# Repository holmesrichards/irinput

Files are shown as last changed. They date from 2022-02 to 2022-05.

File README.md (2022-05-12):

# Barton IR Input

This is a modified version, in Kosmo format, of the [Barton Musical Circuits 078 IR Input](https://www.bartonmusicalcircuits.com/irin/index.html) synth module. Barton describes the original version as follows:

> This module is designed to allow infrared light sources to interact with your synthesizer. The most common household sources of infrared light are fire and remote controls. Infrared LEDs are also readily available to DIYers who wanted to experiment with creating new devices for controlling synthesizers through this module.

The infrared phototransistor that picks up the IR light may be AC or DC coupled to the circuit. Outputs are a CV proportional to the IR signal and a gate that turns on when the CV rises above a threshold set with a panel pot. Another panel pot sets the phototransistor sensitivity.

Modifications to Barton's design are as follows:

* Added 3.5 mm TRS jack for a cable connecting to an external phototransistor and a switch to select internal or external PT. This allows using candles, lighters, etc. to control the synth while not having to have them right in front of it.
* Added gain knob to control gain of amplifier stage. The sensitivity pot (what Barton calls "bias") does vary the size of the signal but gives a small window between too small (no output) and too large (saturated). In AC coupled mode, the size of the AC component may be small, e.g. a few hundred mV, even when the sensitivity pot is set to just below saturation; of course the AC component disappears if the sensitivity pot is then raised further. The gain pot may be used to amplify the AC component to the level of a few volts. In AC mode, the gain range is 1 to 11. In DC mode, the gain pot may be used to help with faint IR sources; the gain range is 1 to 2.
* Added a bicolor indicator LED for the CV output. Brightness is indicative of CV amplitude and color indicates sign (which is positive in DC mode but can go negative in AC mode). 
* Added an indicator LED for saturation. This turns on when the PT emitter voltage is about 10 V. Normally one would want to operate with the sensitivity pot adjusted to just below where this LED comes on continuously while the IR light source is maximum.
* Specified A1M rather than B1M for sensitivity pot.

My modifications, PCB layout, and documentation are licensed Creative Commons Zero (see [LICENSE](LICENSE)). This license is not intended to apply to Michael Barton's intellectual property and no violation of any applicable copyright is intended. Do not use this design for any commercial purpose without first obtaining Barton's permission.

## Current draw
12 mA +12 V, 8 mA -12 V

## Photos

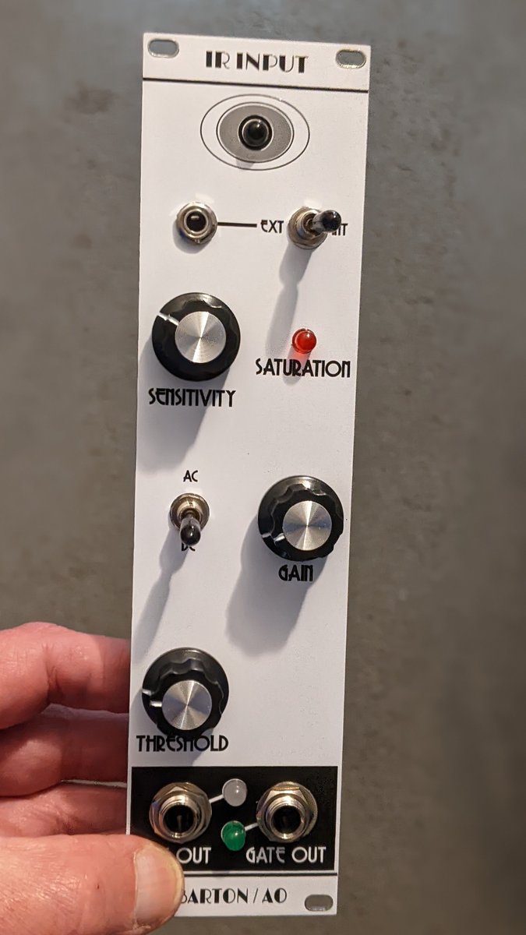
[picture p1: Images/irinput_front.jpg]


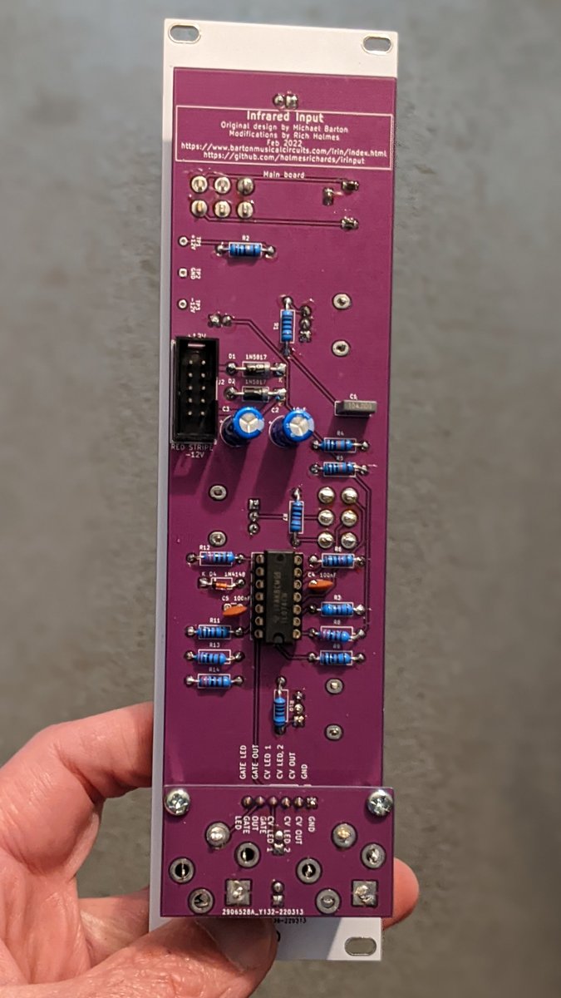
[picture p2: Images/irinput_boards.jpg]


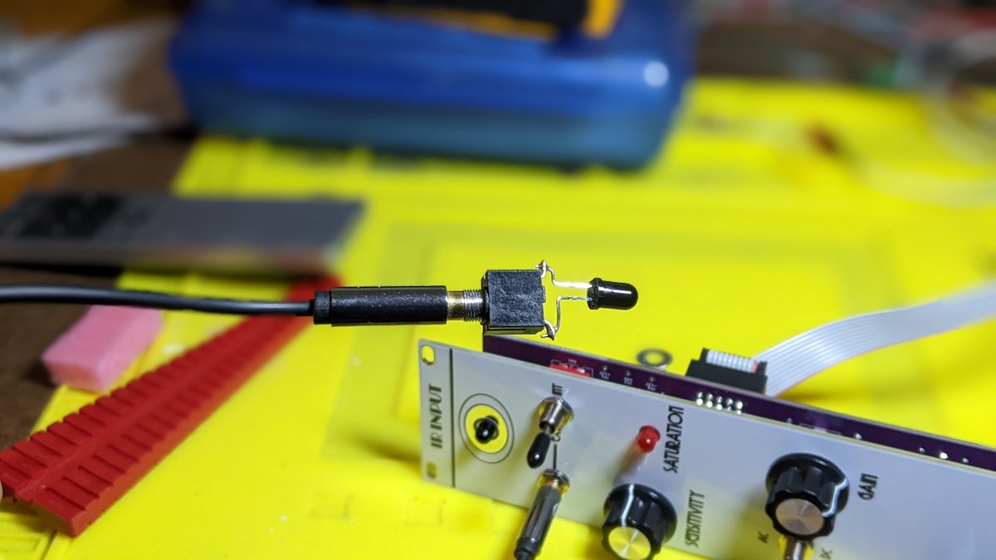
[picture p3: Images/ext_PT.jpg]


## Documentation

* [Schematic](Docs/irinput.pdf)
* PCB layout: [front](Docs/_layout_front.pdf), [back](Docs/_layout_back.pdf)
* [BOM](Docs/irinput_bom.md)
* [Build notes](Docs/irinput_build.md)
* [Blog post 1](https://analogoutputblog.wordpress.com/2022/02/22/playing-with-fire/), [blog post 2](https://analogoutputblog.wordpress.com/2022/03/27/ir-input/)

## GitHub repository

* [https://github.com/holmesrichards/irinput](https://github.com/holmesrichards/irinput)

## Submodules

This repo uses submodules aoKicad and Kosmo_panel, which provide needed libaries for KiCad. To clone:

```
git clone git@github.com:holmesrichards/ir_input.git
git submodule init
git submodule update
```

Alternatively do

```
git clone --recurse-submodules git@github.com:holmesrichards/ir_input.git
```

Or if you download the repository as a zip file, you must also click on the "aoKicad" and "Kosmo\_panel" links on the GitHub page (they'll have "@ something" after them) and download them as separate zip files which you can unzip into this repo's aoKicad and Kosmo\_panel directories.

If desired, copy the files from aoKicad and Kosmo\_panel to wherever you prefer (your KiCad user library directory, for instance, if you have one). Then in KiCad, add symbol libraries 

```
aoKicad/ao_symbols
Kosmo_panel/Kosmo
```
and footprint libraries 
```
aoKicad/ao_tht
Kosmo_panel/Kosmo_panel.
```

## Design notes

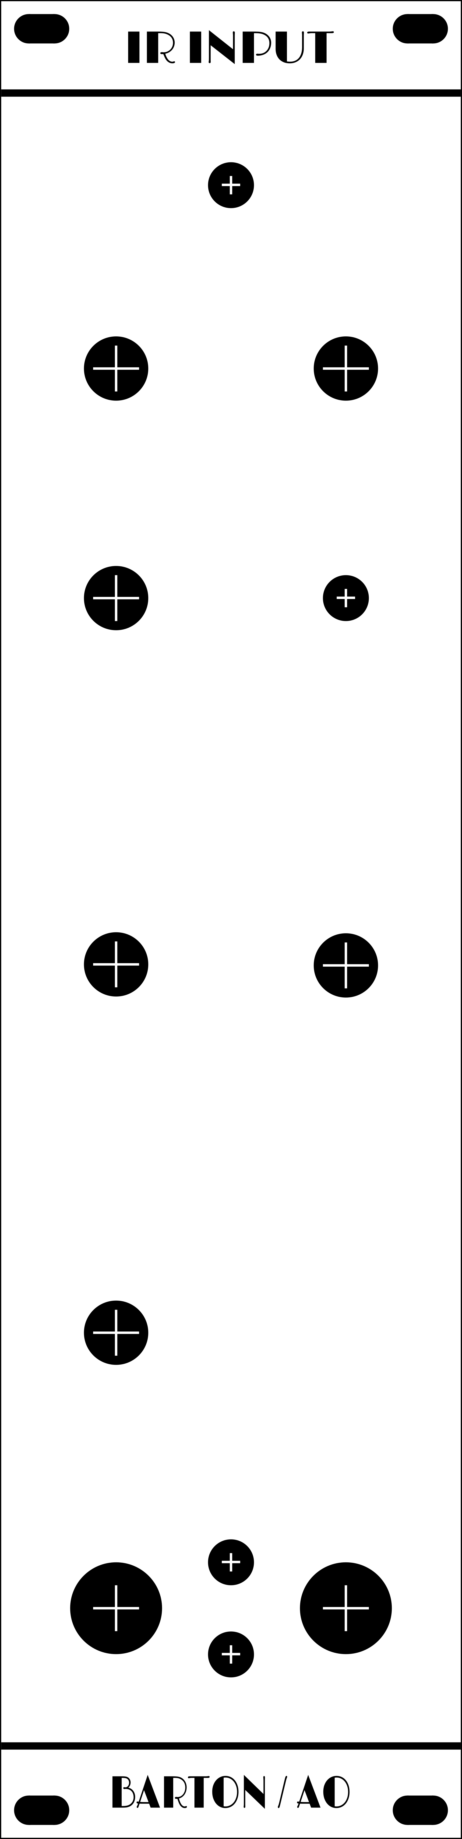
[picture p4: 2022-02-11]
Images/irinput_panel_holes.png

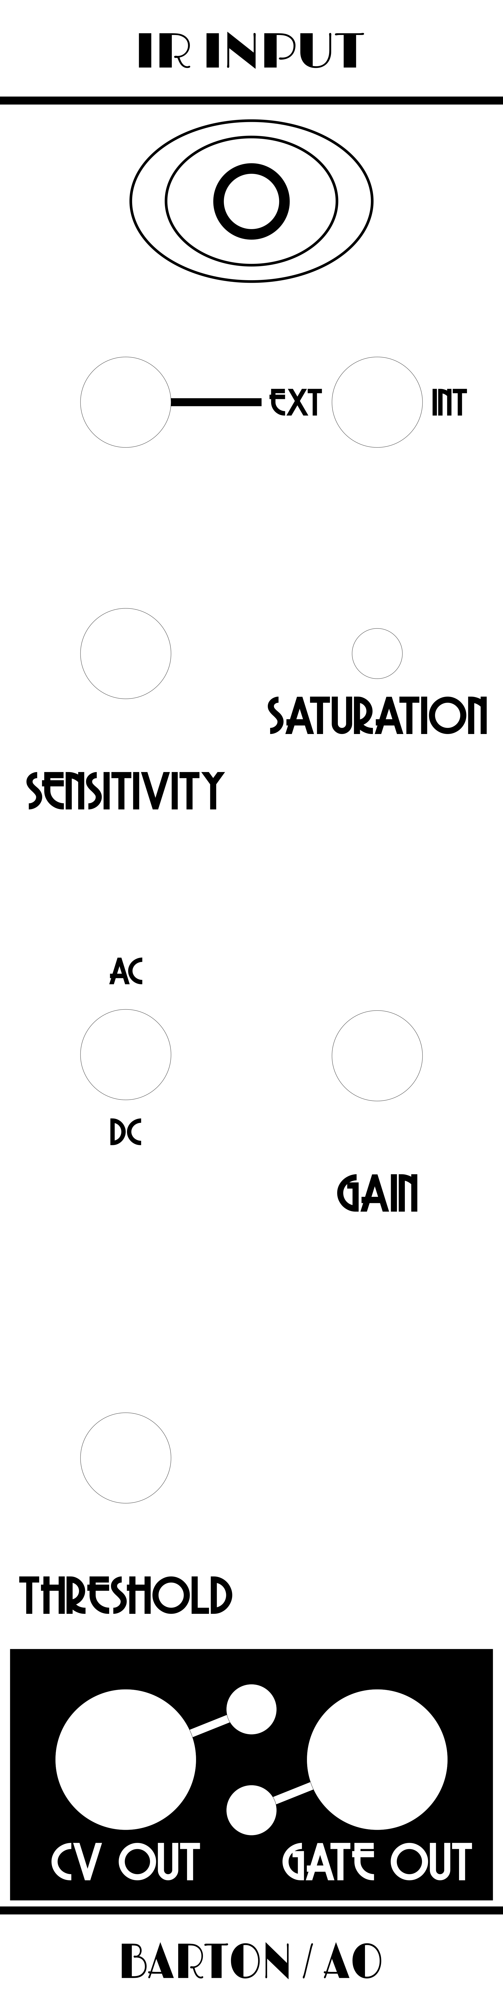
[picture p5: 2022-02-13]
Images/irinput_panel_art.png

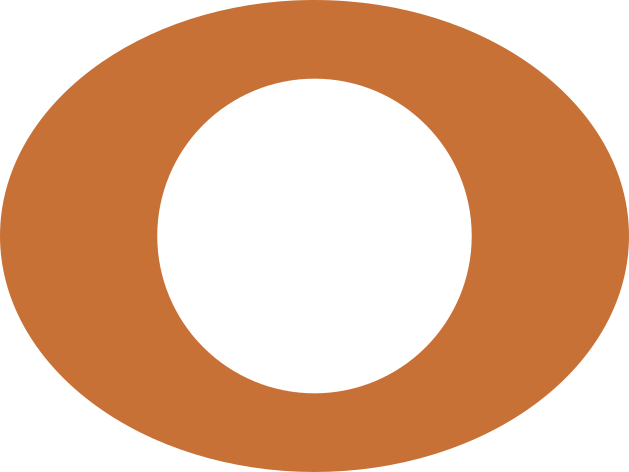
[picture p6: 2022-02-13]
Images/irinput_panel_art_more.png

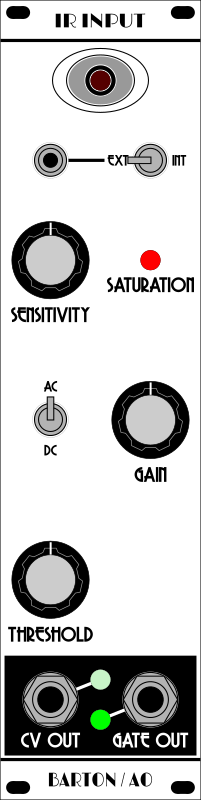
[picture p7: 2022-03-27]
Images/irinput_panel.png

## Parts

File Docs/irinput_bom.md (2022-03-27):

# irinput.kicad_sch BOM

Sun 27 Mar 2022 07:12:55 AM EDT

Generated from schematic by Eeschema 6.0.4-6f826c9f35~116~ubuntu20.04.1

**Component Count:** 40

| Refs | Qty | Component | Description | Vendor | SKU |
| ----- | --- | ---- | --- | ---- | ---- |
| C1 | 1 | 100nF | Film capacitor | Tayda |  |
| C2, C3 | 2 | 10uF | Electrolytic capacitor | Tayda | A-4349 |
| C4, C5 | 2 | 100nF | Ceramic capacitor | Tayda | A-553 |
| D1, D2 | 2 | 1N5817 | Schottky Barrier Rectifier Diode, DO-41 | Tayda | A-159 |
| D3 | 1 | LED_red | Light emitting diode | Tayda | A-1554 |
| D4 | 1 | 1N4148 | Standard switching diode, DO-35 | Tayda | A-157 |
| D5 | 1 | LED_green | Light emitting diode | Tayda | A-1553 |
| D6 | 1 | LED_Dual | Dual LED, bidirectional |  |  |
| J1, J3 | 2 | AudioJack3 | 3.5 mm Audio Jack, 3 Poles (Stereo / TRS) | Tayda | A-1121 |
| J2 | 1 | Synth_power_2x5 | Shrouded 2x5 pin header | Tayda | A-2939 |
| J4 | 1 | Conn_01x06 | 1x6 pin socket, 2.54 mm |  |  |
| J5 | 1 | Conn_01x06 | 1x6 pin header, 2.54 mm |  |  |
| J6, J7 | 2\* | AudioJack2 | 1/4" Audio Jack, 2 Poles (Mono / TS) | Tayda | A-1121 |
| Q1, Q2 | 2\* | TOPS-050 | NPN phototransistor, collector/emitter | Tayda |  |
| R1 | 1 | 100R | Resistor | Tayda |  |
| R2 | 1 | 10R | Resistor | Tayda |  |
| R3 | 1 | 68k | Resistor | Tayda |  |
| R4, R5 | 2 | 100k | Resistor | Tayda |  |
| R6 | 1 | 18k | Resistor | Tayda |  |
| R7 | 1 | 10k | Resistor | Tayda |  |
| R8, R12, R14 | 3 | 2.2k | Resistor | Tayda |  |
| R9, R10, R11 | 3 | 1k | Resistor | Tayda |  |
| R13 | 1 | 2.7k | Resistor | Tayda |  |
| RV1 | 1 | A1M | 9 mm PCB mount potentiometer | Tayda |  |
| RV2, RV3 | 2 | B100k | 9 mm PCB mount potentiometer | Tayda |  |
| SW1, SW2 | 2 | SW_DPDT | Switch, dual pole double throw, on-on |  |  |
| U1 | 1 | TL074 | Quad operational amplifier, DIP-14 | Tayda | A-1138 |
| | 1 | | 14 pin DIP socket | Tayda | |
| | 3 | | knobs | | |

M3 screws, spacers, washers

\* One 3.5 mm stereo jack and one phototransistor are used to make a cable mounted external IR pickup.

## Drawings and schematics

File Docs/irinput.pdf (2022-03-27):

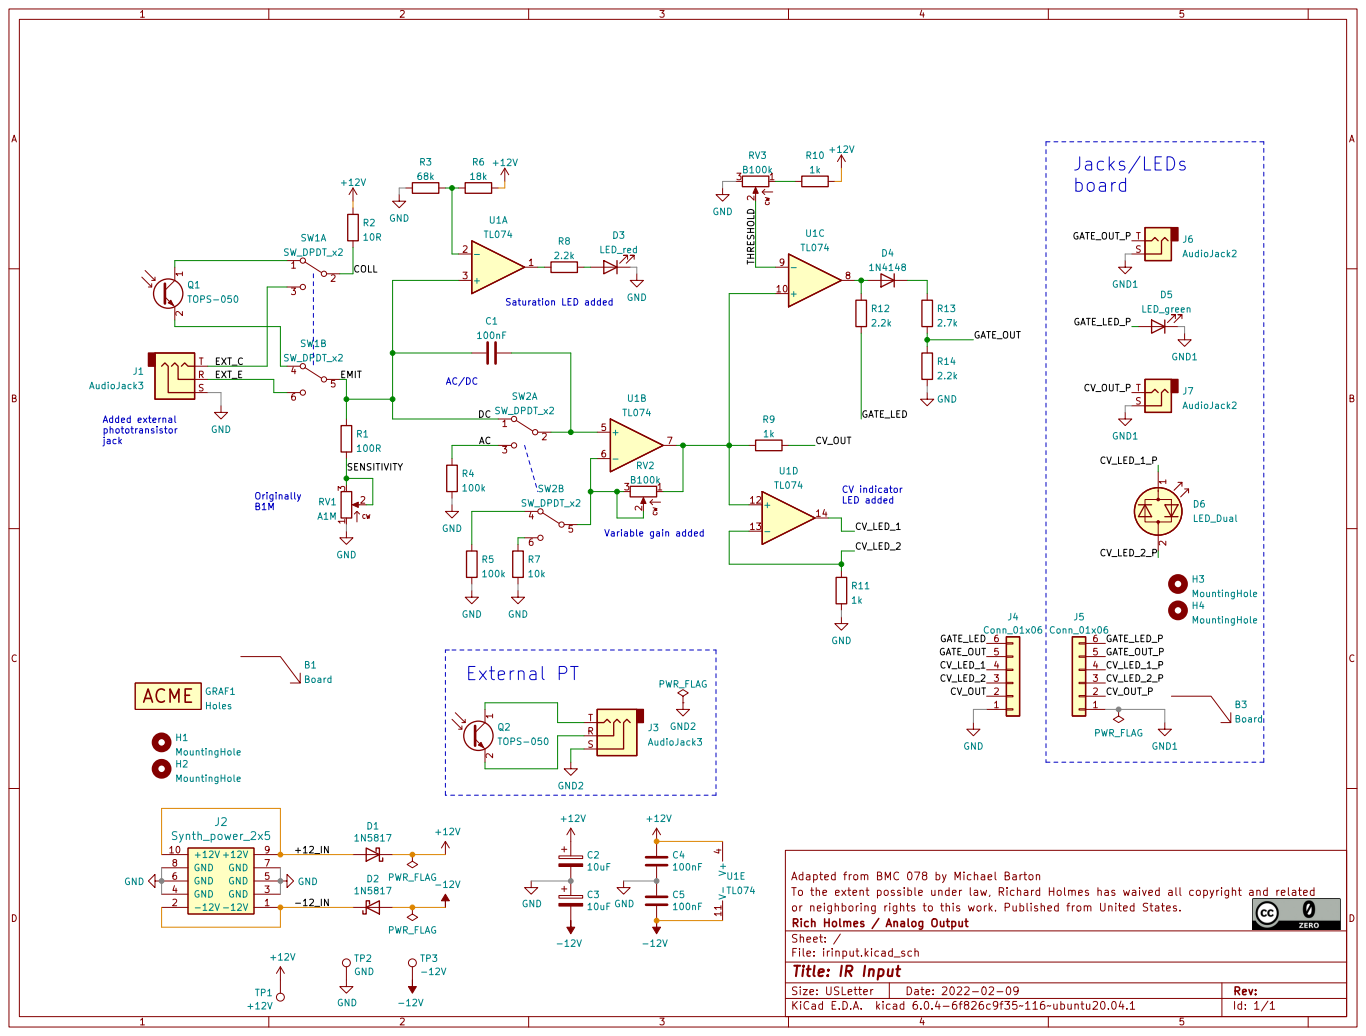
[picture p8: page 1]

or neighboring rights to this work. Published from United States.
File: irinput.kicad_sch Sheet: / Rich Holmes / Analog Output

Id: 1/1 Title: IR Input

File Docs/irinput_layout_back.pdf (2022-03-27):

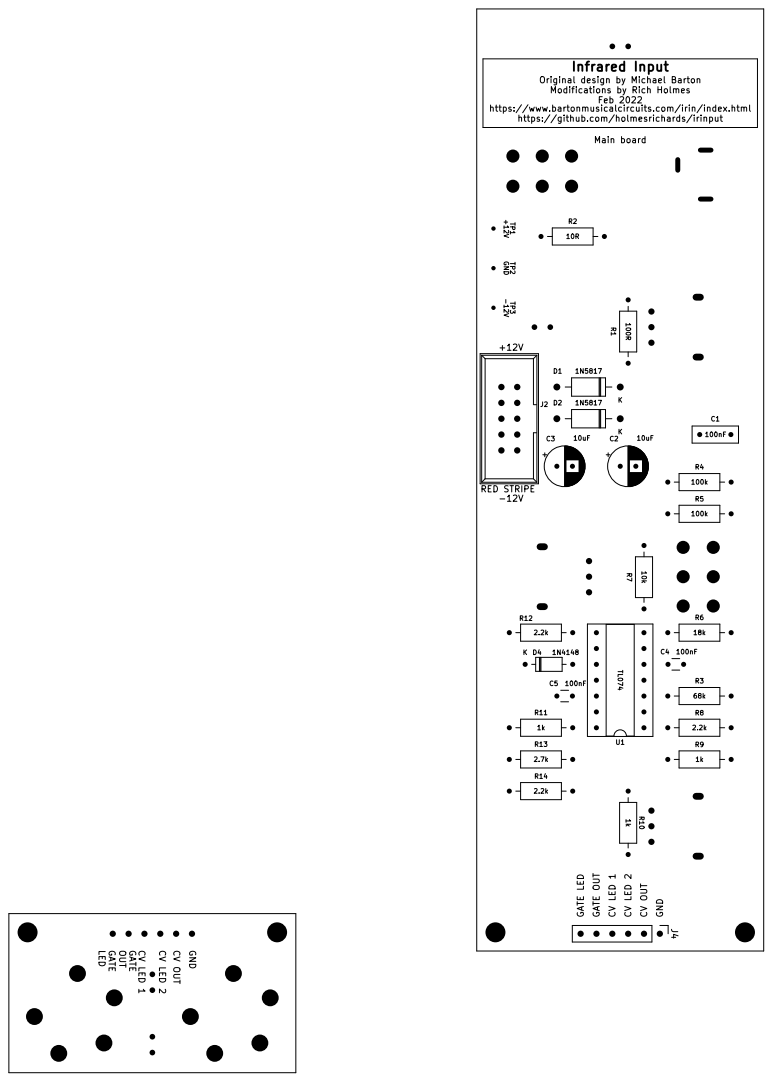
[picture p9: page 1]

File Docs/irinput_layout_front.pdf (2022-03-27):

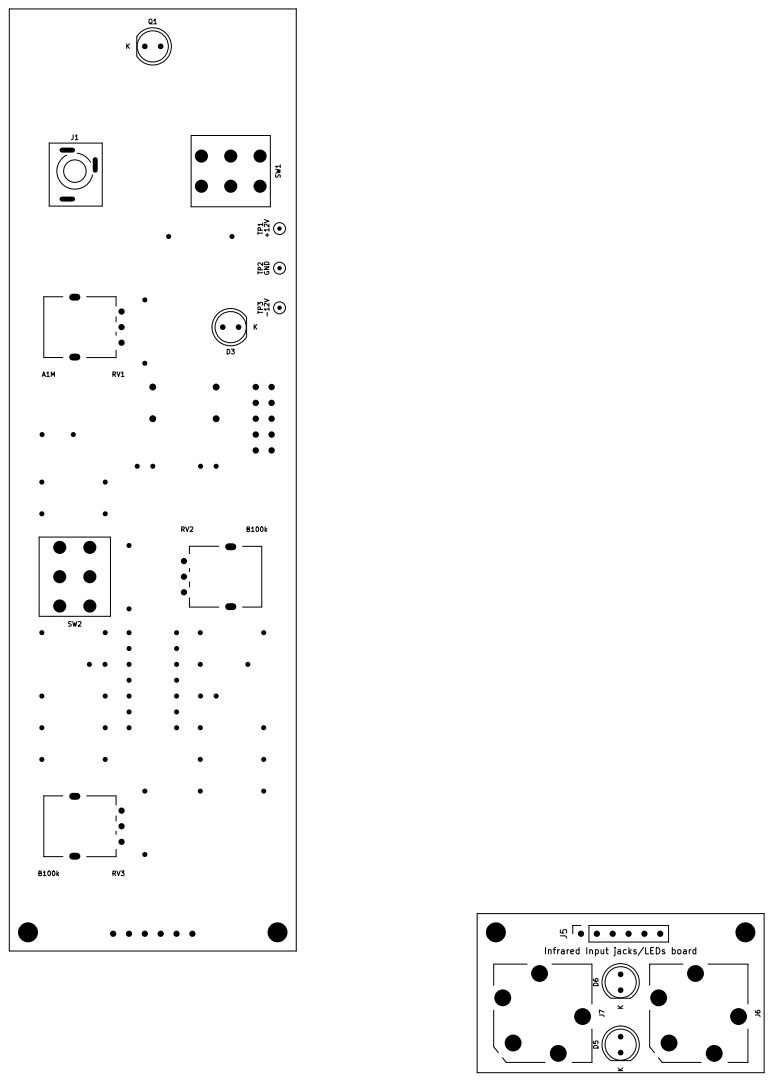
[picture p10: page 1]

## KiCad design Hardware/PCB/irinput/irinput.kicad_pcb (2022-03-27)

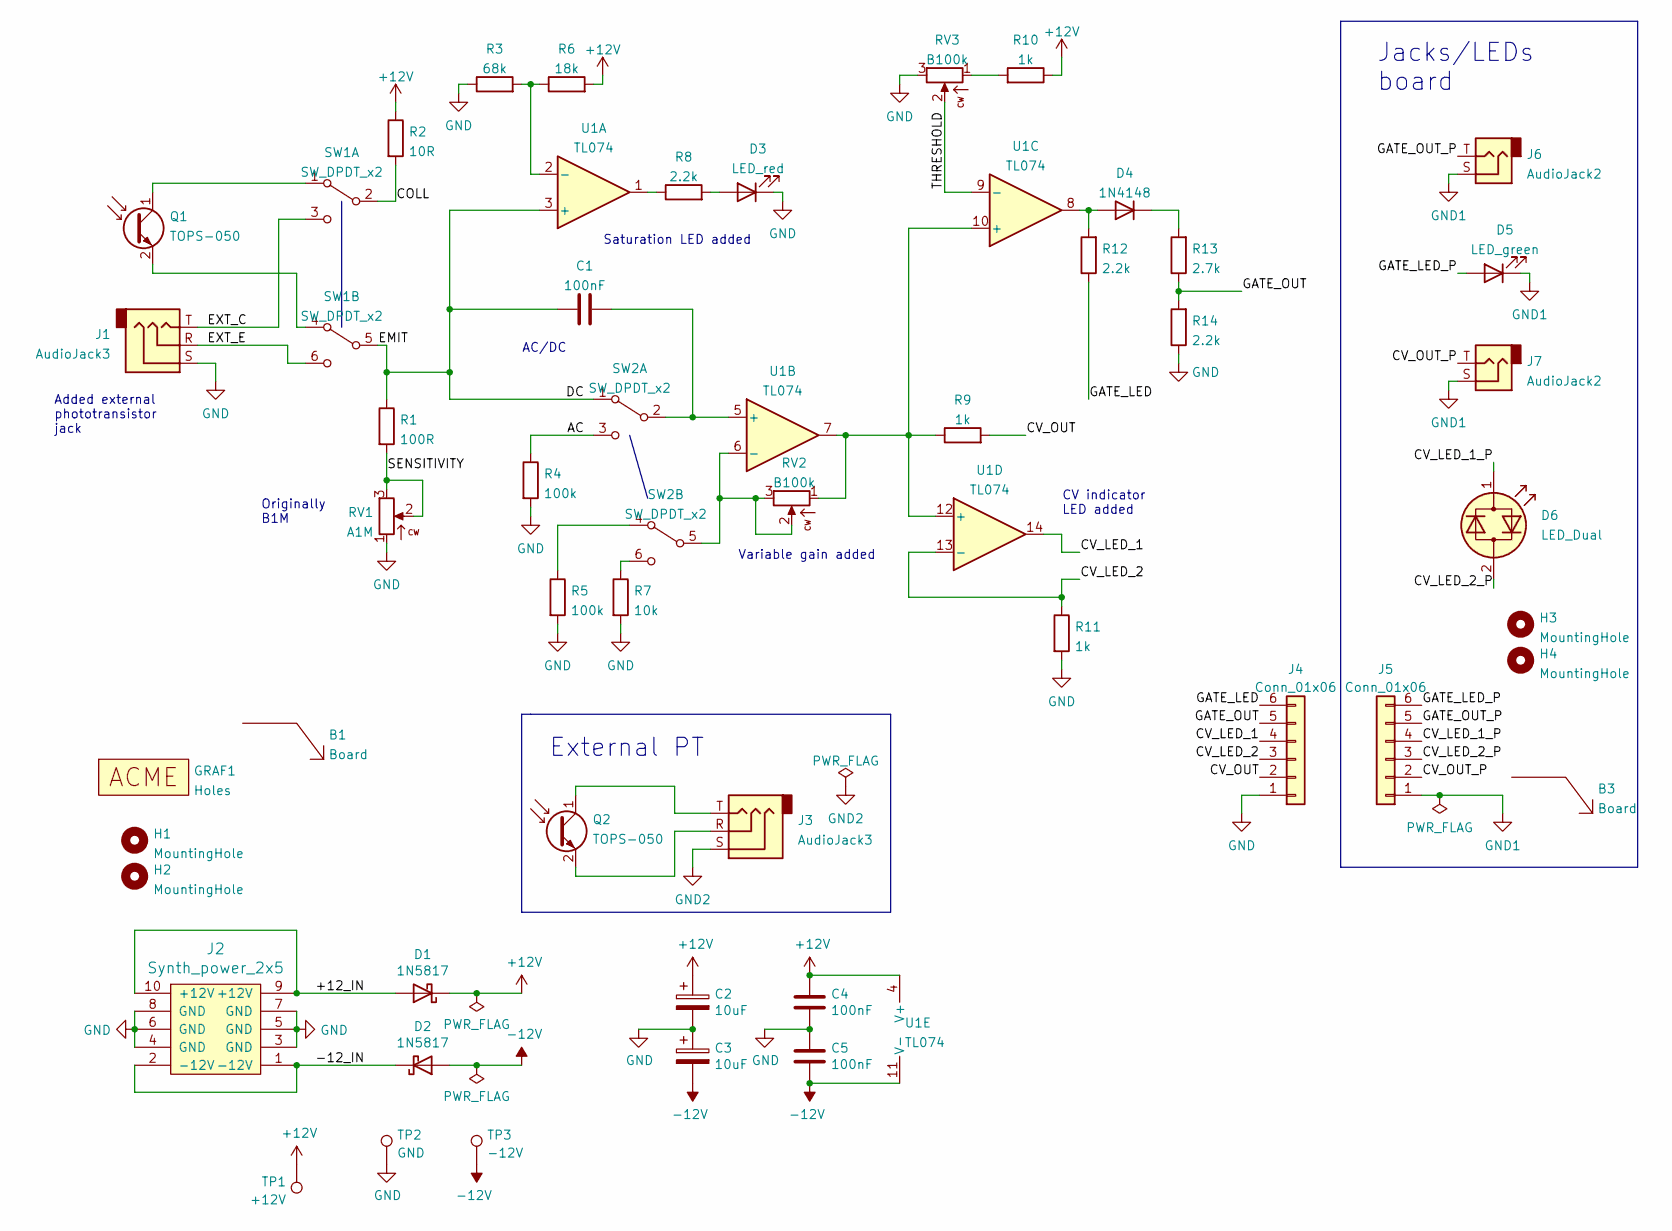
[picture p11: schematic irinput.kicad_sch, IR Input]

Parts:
B1, B3: Board; Board_Marker
C1: 100nF; C_Rect_L7.2mm_W2.5mm_P5.00mm_FKS2_FKP2_MKS2_MKP2
C2, C3: 10uF; CP_Radial_D6.3mm_P2.50mm
C4, C5: 100nF; C_Disc_D3.0mm_W1.6mm_P2.50mm
D1, D2: 1N5817; D_DO-41_SOD81_P10.16mm_Horizontal
D3: LED_red; LED_D5.0mm
D4: 1N4148; D_DO-35_SOD27_P7.62mm_Horizontal
D5: LED_green; LED_D5.0mm
D6: LED_Dual; LED_D5.0mm
GRAF1: Holes; irinput_panel_holes
H1, H2, H3, H4: MountingHole; MountingHole_3.2mm_M3
J1, J3: AudioJack3; Jack_3.5mm_PJ-301CM
J2: Synth_power_2x5; Power_Header
J4: Conn_01x06; PinHeader_1x06_P2.54mm_Vertical
J5: Conn_01x06; PinSocket_1x06_P2.54mm_Vertical
J6, J7: AudioJack2; Jack_6.35mm_PJ_629HAN
Q1, Q2: TOPS-050; LED_D5.0mm
R1: 100R; R_Axial_DIN0207_L6.3mm_D2.5mm_P10.16mm_Horizontal
R2: 10R; R_Axial_DIN0207_L6.3mm_D2.5mm_P10.16mm_Horizontal
R3: 68k; R_Axial_DIN0207_L6.3mm_D2.5mm_P10.16mm_Horizontal
R4, R5: 100k; R_Axial_DIN0207_L6.3mm_D2.5mm_P10.16mm_Horizontal
R6: 18k; R_Axial_DIN0207_L6.3mm_D2.5mm_P10.16mm_Horizontal
R7: 10k; R_Axial_DIN0207_L6.3mm_D2.5mm_P10.16mm_Horizontal
R8, R12, R14: 2.2k; R_Axial_DIN0207_L6.3mm_D2.5mm_P10.16mm_Horizontal
R9, R10, R11: 1k; R_Axial_DIN0207_L6.3mm_D2.5mm_P10.16mm_Horizontal
R13: 2.7k; R_Axial_DIN0207_L6.3mm_D2.5mm_P10.16mm_Horizontal
RV1: A1M; Potentiometer_Alpha_RD901F-40-00D_Single_Vertical_centered
RV2, RV3: B100k; Potentiometer_Alpha_RD901F-40-00D_Single_Vertical_centered
SW1, SW2: SW_DPDT_x2; DPDT-toggle-switch-1M-seriesx
TP1: +12V; TestPoint_THTPad_D1.5mm_Drill0.7mm
TP2: GND; TestPoint_THTPad_D1.5mm_Drill0.7mm
TP3: -12V; TestPoint_THTPad_D1.5mm_Drill0.7mm
U1: TL074; DIP-14_W7.62mm_Socket_LongPads

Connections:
+12V: C2.1, C4.1, D1.1 (K), R2.1, R6.2, R10.1, TP1.1, U1.4 (V+)
-12V: C3.2, C5.2, D2.2 (A), TP3.1, U1.11 (V-)
/+12_IN: D1.2 (A), J2.9 (+12V), J2.10 (+12V)
/-12_IN: D2.1 (K), J2.1 (-12V), J2.2 (-12V)
/AC: R4.1, SW2.3 (C)
/COLL: R2.2, SW1.2 (B)
/CV_LED_1: J4.4, U1.14
/CV_LED_1_P: D6.1 (KA), J5.4
/CV_LED_2: J4.3, R11.1, U1.13 (-)
/CV_LED_2_P: D6.2 (AK), J5.3
/CV_OUT: J4.2, R9.2
/CV_OUT_P: J5.2, J7.T
/DC: C1.1, R1.1, SW1.5 (B), SW2.1 (A), U1.3 (+)
/EXT_C: J1.T, SW1.3 (C)
/EXT_E: J1.R, SW1.6 (C)
/GATE_LED: J4.6, R12.1
/GATE_LED_P: D5.2 (A), J5.6
/GATE_OUT: J4.5, R13.1, R14.2
/GATE_OUT_P: J5.5, J6.T
/SENSITIVITY: R1.2, RV1.2, RV1.3
/THRESHOLD: RV3.2, U1.9 (-)
GND: C2.2, C3.1, C4.2, C5.1, D3.1 (K), J1.S, J2.3 (GND), J2.4 (GND), J2.5 (GND), J2.6 (GND), J2.7 (GND), J2.8 (GND), J4.1, R3.1, R4.2, R5.2, R7.2, R11.2, R14.1, RV1.1, RV3.3, TP2.1
GND1: D5.1 (K), J5.1, J6.S, J7.S
unnamed: C1.2, SW2.2 (B), U1.5 (+)
unnamed: D3.2 (A), R8.2
unnamed: D4.1 (K), R13.2
unnamed: D4.2 (A), R12.2, U1.8
unnamed: J3.R, Q2.2 (E)
unnamed: J3.T, Q2.1 (C)
unnamed: Q1.1 (C), SW1.1 (A)
unnamed: Q1.2 (E), SW1.4 (A)
unnamed: R3.2, R6.1, U1.2 (-)
unnamed: R5.1, SW2.4 (A)
unnamed: R7.1, SW2.6 (C)
unnamed: R8.1, U1.1
unnamed: R9.1, RV2.1, U1.7, U1.10 (+), U1.12 (+)
unnamed: R10.2, RV3.1
unnamed: RV2.2, RV2.3, SW2.5 (B), U1.6 (-)

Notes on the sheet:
External PT
Saturation LED added
AC/DC
Jacks/LEDs board
Variable gain added
Originally B1M
CV indicator LED added
Added external phototransistor jack

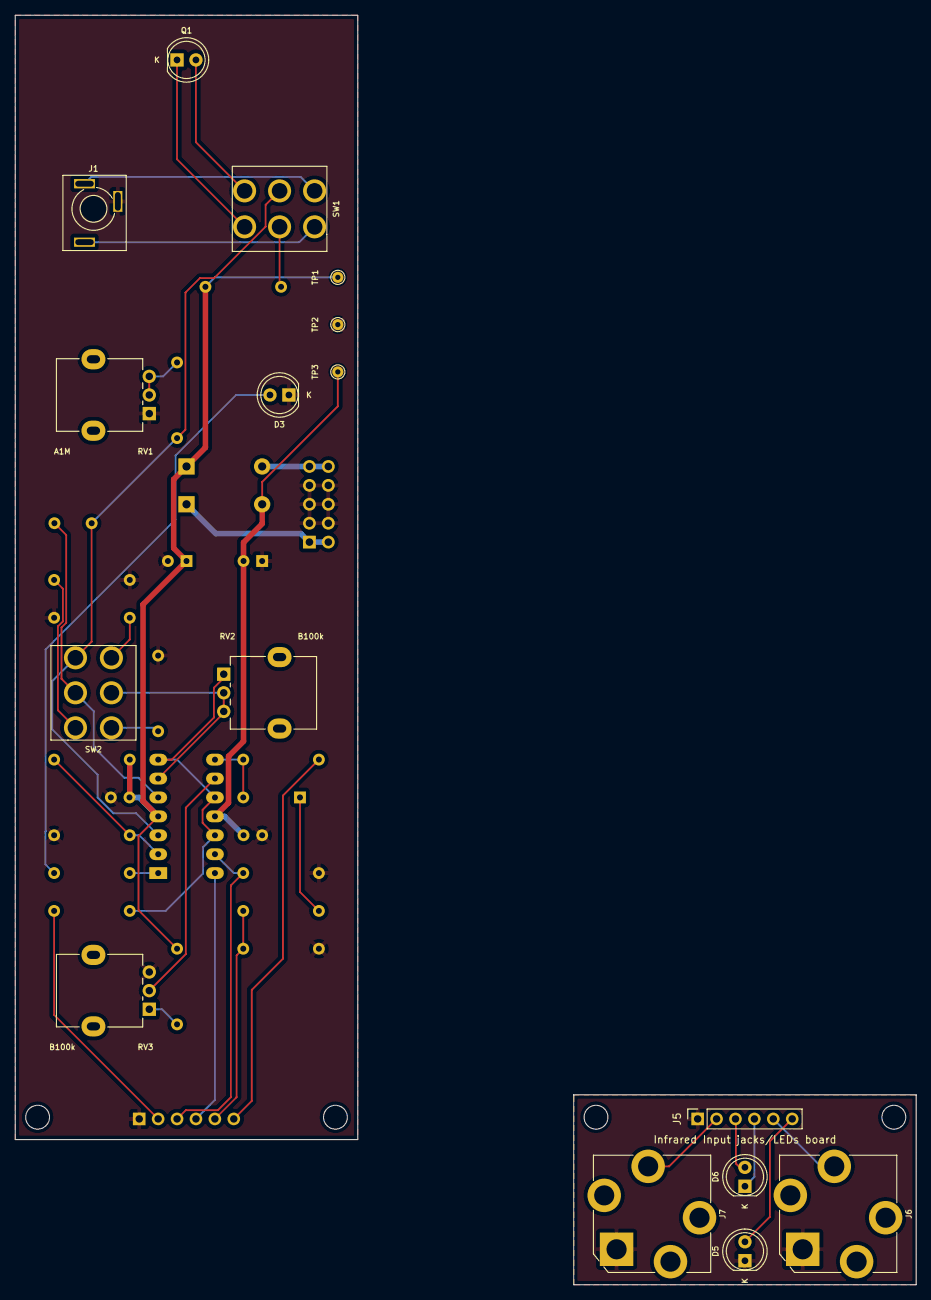
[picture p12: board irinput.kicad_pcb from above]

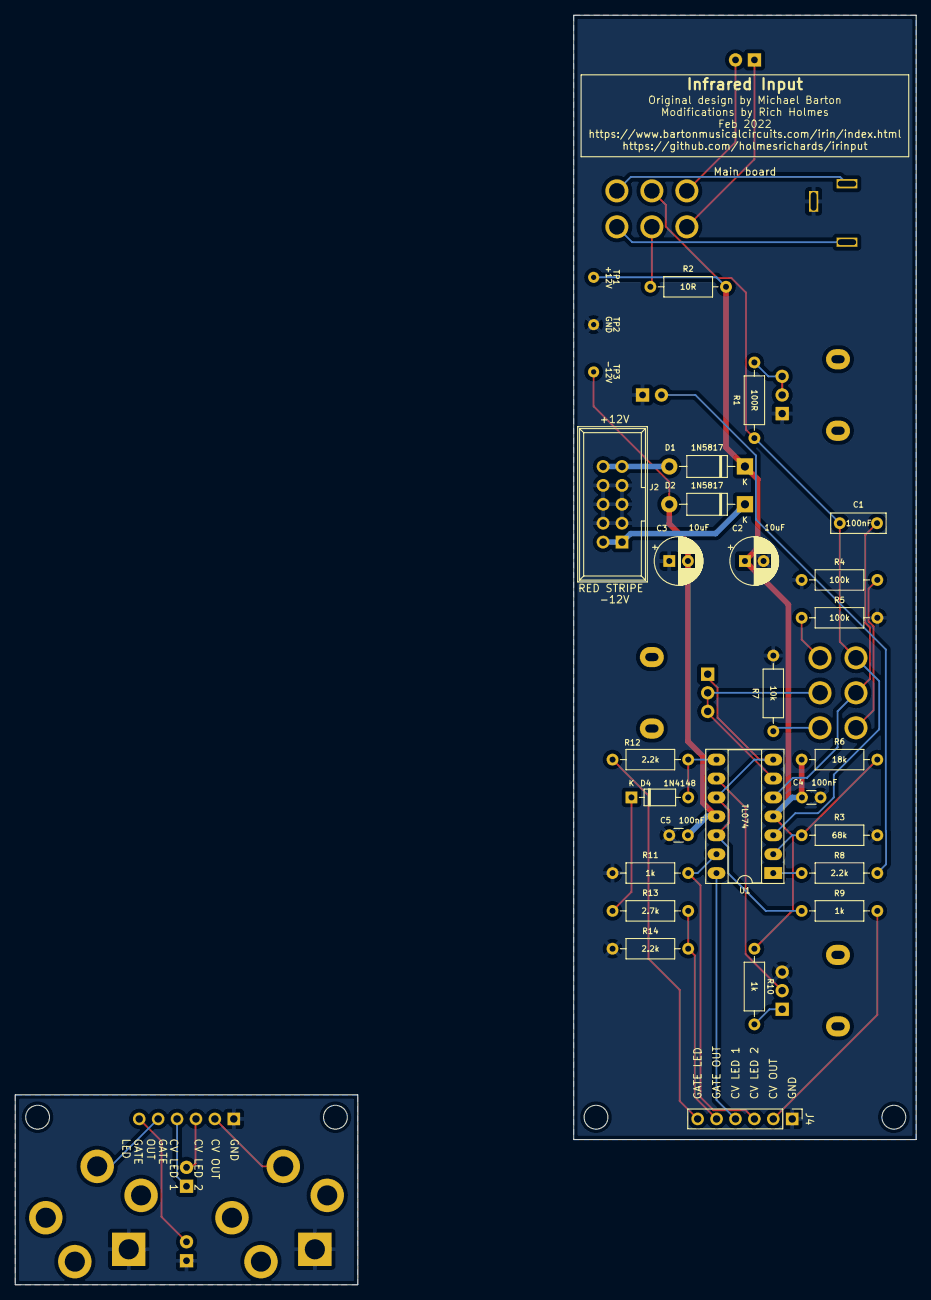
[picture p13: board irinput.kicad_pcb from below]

Board: 2 copper layers, 46.0 x 151.0 mm, 48 parts (25 on the bottom side), 36 nets.

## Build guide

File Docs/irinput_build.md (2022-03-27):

# IR input build notes

There isn't much to say about building this module. As usual, start with the shortest components (resistors, diodes) and finish with the tallest (headers, electrolytic caps).

Notice that on the main board the pots, switches, saturation LED, phototransistor and external PT jack will go on the PCB side opposite the rest of the components. Before soldering them, put the 6 pin header and socket together and sandwich them between the front and main PCBs. Use screws, washers, and spacers to secure the two boards together. Once they're aligned and held in place, solder the headers. Then place the pots, jacks, switches, LEDs, and phototransistors in their places on the PCBs, put the panel on top of them, and fasten it down with nuts on several of the jacks and pots. The LEDs go with their short lead in the hole marked K (for "kathode"). The TOPS-050 phototransistor's emitter is the long leg and the collector is the short leg (other phototransistors may be the opposite); put the short leg in the hole marked K (for "kollektor"). Turn the assembly over, make sure all panel components are flush to the back of the panel, and solder these parts to the PCBs. You're done.

For the external phototransistor, solder the collector leg to the tip terminal and the emitter leg to the ring terminal of a TRS jack. The sleeve terminal should not be connected and can be clipped off. Then use a stereo cable to connect it to the module.

I decided I thought of the bottom pot as a threshold control, rather than a gate sensitivity control, which meant I wanted it opposite the way Barton did — I wanted clockwise to be maximum threshold, not maximum sensitivity (minimum threshold). But then I confused myself and my design ended up making it the same as Barton's, though it's labelled "Threshold". If this really bothers you you can kludge it so pin 1 (CCW) connects to ground and pin 3 (CW) connects to R10, instead of vice versa, or you can do what I did and just leave it alone and pretend it's labeled "Gate Sensitivity".

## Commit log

2021-10-01 Expand label, move switch, add eye
2021-10-02 Library updates, panel design and Gerbers
    [irinput_panel.kicad_pcb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]
2021-12-02 Panel art tweak
    [irinput_panel.kicad_pcb]
2022-02-10 Initial PCB design, revised panel, notes
    [irinput.kicad_pcb, irinput.kicad_sch]
2022-02-11 Revised schematic to buffer input to variable gain stage
    [irinput.kicad_pcb, irinput.kicad_sch]
2022-02-11 Revert to using no inverting stages, put gain control on non inverting stage. Add saturation LED.
    [irinput.kicad_pcb, irinput.kicad_sch]
2022-02-12 Corrected cap, initial BOM
    [irinput.kicad_sch]
2022-02-13 Silkscreen cleanup, revised panel
    [irinput.kicad_pcb, irinput.kicad_sch, irinput_panel.kicad_pcb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]
2022-03-27 Catch up to 1st fab run version
    [irinput.kicad_pcb, irinput.kicad_sch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]
